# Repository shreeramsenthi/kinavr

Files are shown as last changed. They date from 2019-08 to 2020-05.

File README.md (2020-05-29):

kinavr
=======================================================================================

Hardware and firmware for automated approach to the recording of animal kinematics using inertial measurement units and AVR microcontrollers.

The schematics and board layouts for the modular data loggers can be found in the `board_design` subdirectory.
The source code for the firmware for data loggers make up the rest of the repository.

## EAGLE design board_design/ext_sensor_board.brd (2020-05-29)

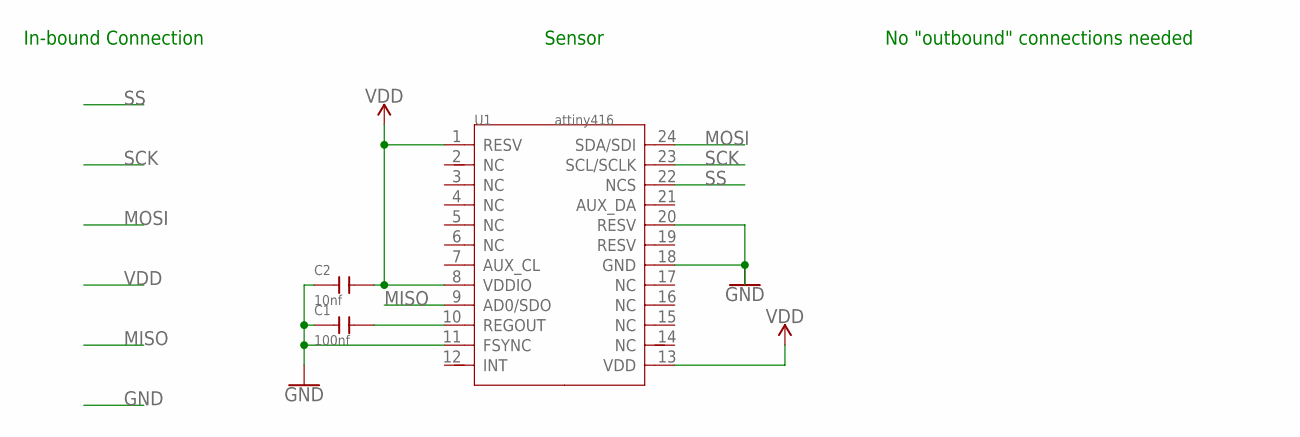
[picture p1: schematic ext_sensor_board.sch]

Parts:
C1: 100nf; C0402
C2: 10nf; C0402
U1: attiny416; QFN24G-0.4-3X3MM

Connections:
GND: C1.1, C2.1, U1.11 (FSYNC), U1.18 (GND), U1.20 (RESV)
MISO: U1.9 (AD0/SDO)
MOSI: U1.24 (SDA/SDI)
unnamed: C1.2, U1.10 (REGOUT)
SCK: U1.23 (SCL/SCLK)
SS: U1.22 (NCS)
VDD: C2.2, U1.1 (RESV), U1.8 (VDDIO), U1.13 (VDD)

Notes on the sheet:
Sensor
In-bound Connection
No "outbound" connections needed

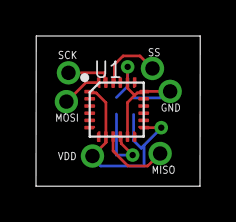
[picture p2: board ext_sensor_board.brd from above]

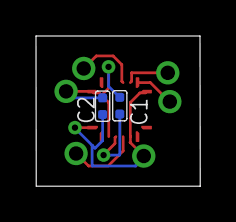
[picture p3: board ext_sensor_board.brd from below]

Board: 2 copper layers, 9.1 x 8.3 mm, 3 parts (2 on the bottom side), 3 nets.

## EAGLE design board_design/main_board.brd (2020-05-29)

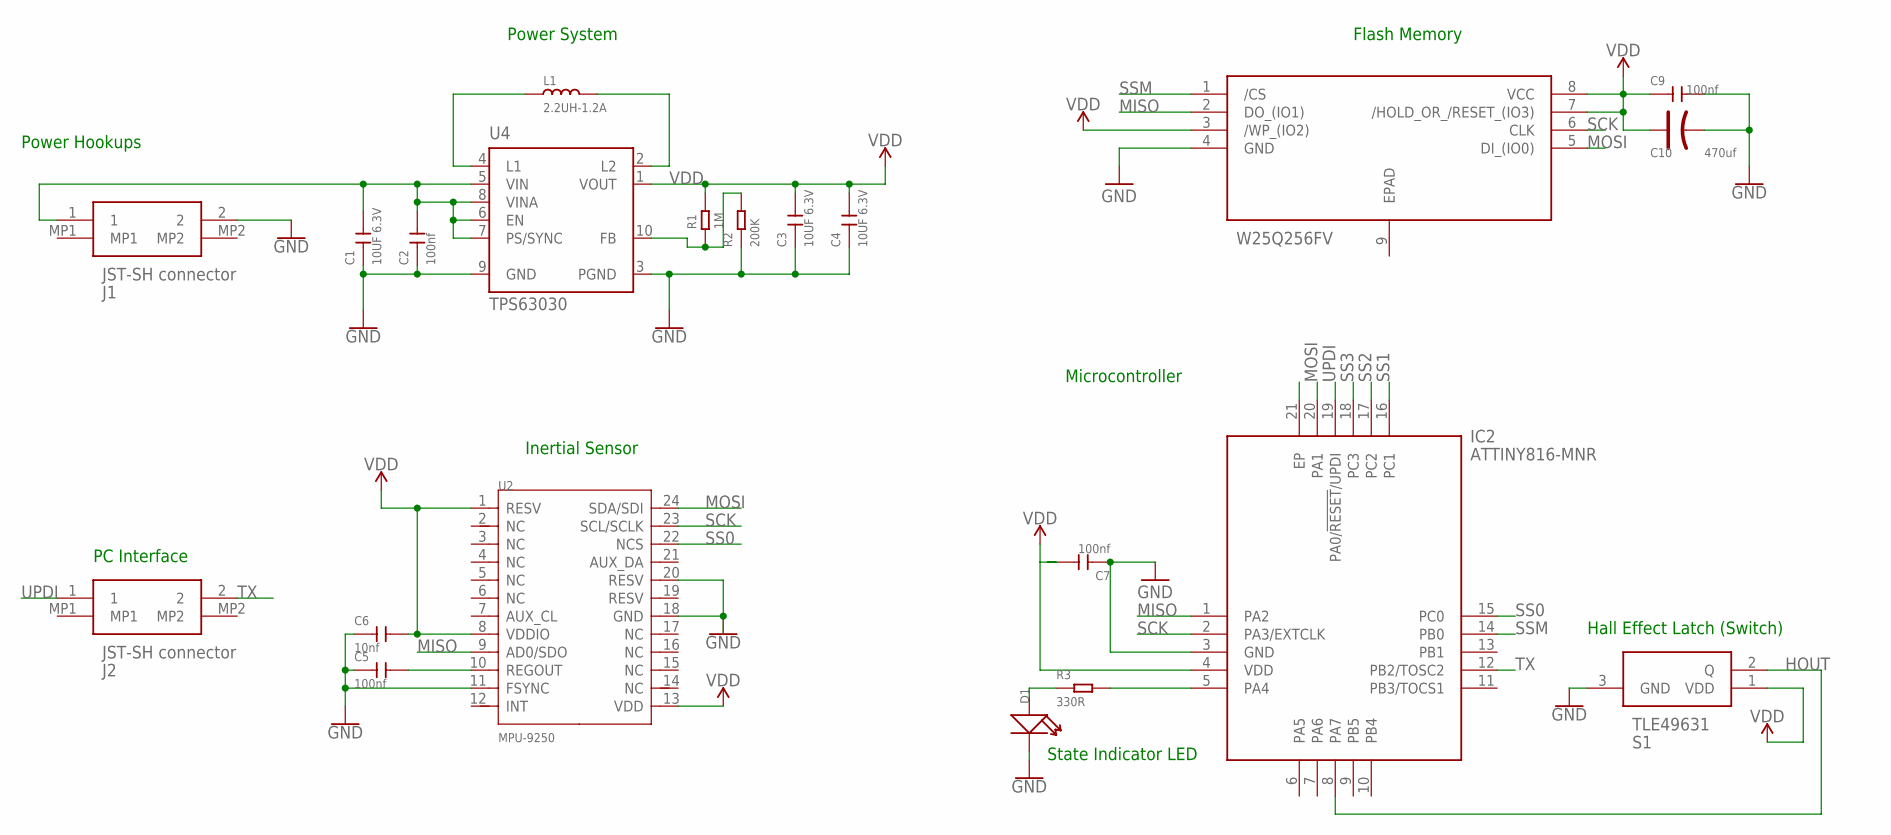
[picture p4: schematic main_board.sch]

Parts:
C1, C3, C4: 10UF 6.3V; C0603
C2, C7, C9: 100nf; C0603
C5: 100nf; C0402
C6: 10nf; C0402
C10: 470uf; AVX-D
D1: YELLOW-0603; LED-0603
IC1: W25Q256FV; SON127P800X600X80-9N
IC2: ATTINY816-MNR; QFN40P300X300X90-21N
J1, J2: JST-SH connector; BM02BSRSSTBLFSN
L1: 2.2UH-1.2A; L0805
R1: 1M; R0402
R2: 200K; R0603
R3: 330R; R0402
S1: TLE49631; SOT95P240X110-3N
U2: MPU-9250; QFN24G-0.4-3X3MM
U4: TPS63030; DRC-S-PVSON-N10

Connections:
GND: C1.1, C2.1, C3.1, C4.1, C5.1, C6.1, C7.1, C9.2, C10.-, D1.-, IC1.4 (GND), IC2.3 (GND), J1.2, R2.1, S1.3 (GND), U2.11 (FSYNC), U2.18 (GND), U2.20 (RESV), U4.3 (PGND), U4.9 (GND)
HOUT: IC2.8 (PA7), S1.2 (Q)
MISO: IC1.2 (DO_(IO1)), IC2.1 (PA2), U2.9 (AD0/SDO)
MOSI: IC1.5 (DI_(IO0)), IC2.20 (PA1), U2.24 (SDA/SDI)
unnamed: D1.+, R3.1
unnamed: L1.1, U4.4 (L1)
unnamed: L1.2, U4.2 (L2)
unnamed: R1.1, R2.2, U4.10 (FB)
unnamed: C1.2, C2.2, J1.1, U4.5 (VIN), U4.6 (EN), U4.7 (PS/SYNC), U4.8 (VINA)
unnamed: IC2.5 (PA4), R3.2
unnamed: C5.2, U2.10 (REGOUT)
SCK: IC1.6 (CLK), IC2.2 (PA3/EXTCLK), U2.23 (SCL/SCLK)
SS0: IC2.15 (PC0), U2.22 (NCS)
SS1: IC2.16 (PC1)
SS2: IC2.17 (PC2)
SS3: IC2.18 (PC3)
SSM: IC1.1 (/CS), IC2.14 (PB0)
TX: IC2.12 (PB2/TOSC2), J2.2
UPDI: IC2.19 (PA0/!RESET!/UPDI), J2.1
VDD: C3.2, C4.2, C6.2, C7.2, C9.1, C10.+, IC1.3 (/WP_(IO2)), IC1.7 (/HOLD_OR_/RESET_(IO3)), IC1.8 (VCC), IC2.4 (VDD), R1.2, S1.1 (VDD), U2.1 (RESV), U2.8 (VDDIO), U2.13 (VDD), U4.1 (VOUT)

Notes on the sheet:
Microcontroller
Power Hookups
PC Interface
Hall Effect Latch (Switch)
State Indicator LED
Power System
Flash Memory
Inertial Sensor

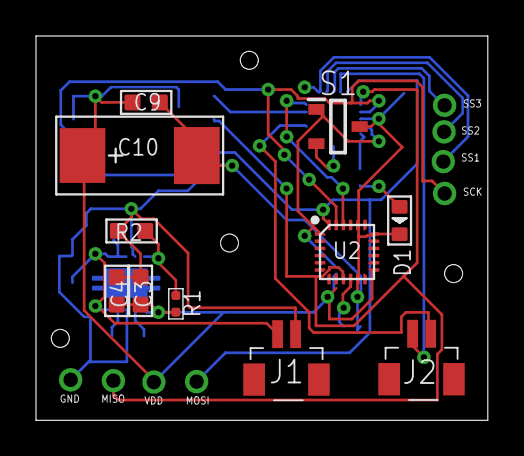
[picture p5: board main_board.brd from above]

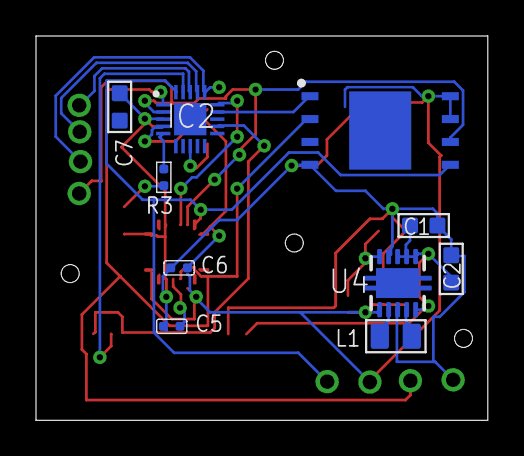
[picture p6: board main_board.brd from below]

Board: 2 copper layers, 25.1 x 21.4 mm, 21 parts (10 on the bottom side), 17 nets.

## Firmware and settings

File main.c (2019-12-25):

#define F_CPU 16000000UL

#include <avr/io.h>
#include <avr/interrupt.h>
#include <util/delay.h>

const int LED_PIN = PIN4_bm;    // PORT A
const int SWITCH_PIN = PIN7_bm; // PORT A

void blink (int blinks) {
  for(int i = 0; i < blinks; i ++){
    PORTA_OUTSET = LED_PIN;
    _delay_ms(500);
    PORTA_OUTCLR = LED_PIN;
    _delay_ms(500);
  }
}

#include "com/uart.c"
#include "com/spi.c"

#include "modes/do.c"
#include "modes/dc.c"

int main () {
  // Setup master clock speed
  CPU_CCP = CCP_IOREG_gc; // Unlock protected io regs
  CLKCTRL_MCLKCTRLB = 0; // set clock speed to 16MHz

  // Hall effect switch setup
  PORTA_DIRCLR = SWITCH_PIN;
  PORTA_PIN7CTRL = PORT_PULLUPEN_bm;

  // LED setup
  PORTA_DIRSET = LED_PIN;
  PORTA_OUTSET = LED_PIN;

  while(1){
    if (~PORTA_IN & SWITCH_PIN) { // check if switch is low
      PORTA_OUTCLR = LED_PIN;
      _delay_ms(5000);
      if(PORTA_IN & SWITCH_PIN) // if switched to high
        collect_data();
      else
        output_data();
    }
    _delay_ms(1000);
  }
}

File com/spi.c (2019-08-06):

#include "mpu9250.h"

const uint8_t MOSI = PIN1_bm; // PORT A
const uint8_t SCK = PIN3_bm; // PORT A
const uint8_t SS_MEM = PIN0_bm; // PORT B
const uint8_t SS_SEN0 = PIN0_bm; // PORT C
const uint8_t SS_SEN1 = PIN1_bm; // PORT C
const uint8_t SS_SEN2 = PIN2_bm; // PORT C
const uint8_t SS_SEN3 = PIN3_bm; // PORT C
const uint8_t SS_SEN = PIN0_bm | PIN1_bm | PIN2_bm | PIN3_bm; // PORT C

/*------------------------------------------*/
/*               Low Level                  */
/*------------------------------------------*/

void spi_init() {
  // Setup output pins, drive SS lines high
  PORTA_DIRSET = MOSI | SCK;

  PORTB_DIRSET = SS_MEM;
  PORTB_OUTSET = SS_MEM;

  PORTC_DIRSET = SS_SEN;
  PORTC_OUTSET = SS_SEN;

  SPI0_CTRLB = 3; // SPI MODE 3
  SPI0_CTRLA = SPI_MASTER_bm |
               SPI_PRESC_DIV16_gc |
               SPI_ENABLE_bm; // Enable SPI in fast master mode
}

unsigned char spi_transfer (unsigned char data) {
  SPI0_DATA = data; // Place data in transfer register
  while(!(SPI0_INTFLAGS & SPI_IF_bm)); // Wait until SPI Interrupt Flag is set
  return(SPI0_DATA);
}

/*------------------------------------------*/
/*            Flash Functions               */
/*------------------------------------------*/

void flash_send_address (uint32_t addr) { //Sends 3 byte addresses over SPI
  // Convert address to 3 bytes and send
  spi_transfer((addr >> 16) & 0xFF);
  spi_transfer((addr >> 8) & 0xFF);
  spi_transfer(addr & 0xFF);
}

void flash_wait_for_ready ()
{
  PORTB_OUTCLR = SS_MEM; // Set SS low
  spi_transfer(0x05); // Read status register 1 command
  while((spi_transfer(0) & 1)); // Keep reading until least bit = 0, indicates not chip isn't busy
  PORTB_OUTSET = SS_MEM; // Set SS High
}

void flash_write_enable () {
  PORTB_OUTCLR = SS_MEM; // Set SS low
  spi_transfer(0x06); //Write enable
  PORTB_OUTSET = SS_MEM; // Set SS High
}

// For external use
void flash_start_read (uint32_t addr) {
  flash_wait_for_ready();

  PORTB_OUTCLR = SS_MEM;   // Set SS low
  spi_transfer(0x03); // Read Command
  flash_send_address(addr);
}

void flash_start_write (uint32_t addr){
  flash_wait_for_ready();
  flash_write_enable();

  PORTB_OUTCLR = SS_MEM; // Set SS low
  spi_transfer(0x02); // Write command
  flash_send_address(addr);
}

void flash_end_rw () {
  PORTB_OUTSET = SS_MEM;   // Set SS high
}

void flash_write_single (uint32_t addr, unsigned char data){
  flash_wait_for_ready();
  flash_write_enable();

  PORTB_OUTCLR = SS_MEM; // Set SS low
  spi_transfer(0x02); // Write command
  flash_send_address(addr);
  spi_transfer(data);
  PORTB_OUTSET = SS_MEM; // End Write
}

void flash_block_erase (uint32_t addr){
  flash_wait_for_ready();
  flash_write_enable();

  PORTB_OUTCLR = SS_MEM; // Set SS low
  spi_transfer(0x52); // Block Erase command
  flash_send_address(addr);
  PORTB_OUTSET = SS_MEM; // End Write
}

void flash_chip_erase (){
  flash_wait_for_ready();
  flash_write_enable();

  PORTB_OUTCLR = SS_MEM; // Set SS low
  spi_transfer(0xC7); // Chip Erase command
  PORTB_OUTSET = SS_MEM; // End Write
}

/*------------------------------------------*/
/*            Sensor Functions              */
/*------------------------------------------*/

uint8_t mpu_reg_transfer (uint8_t SS, uint8_t reg, uint8_t val) {
  PORTC_OUTCLR = SS;
  spi_transfer(reg);
  uint8_t data = spi_transfer(val);
  PORTC_OUTSET = SS;
  return(data);
}

void mpu_write_register (uint8_t SS, uint8_t addr, uint8_t data) {
  mpu_reg_transfer(SS, addr, data);
  _delay_ms(10);
}

void mpu_start_read (uint8_t SS, uint8_t addr) {
  PORTC_OUTCLR = SS;
  spi_transfer(addr | 0x80); // Strip bank info, add read flag
}

void mpu_end_read (uint8_t SS) {
  PORTC_OUTSET = SS;
}

void mag_write_reg (uint8_t SS, uint8_t reg, uint8_t data) {
  mpu_write_register(SS, MPU9250_I2C_SLV0_ADDR, 0x0C); // Set i2c Address to write
  mpu_write_register(SS, MPU9250_I2C_SLV0_REG, reg); // Set register address
  mpu_write_register(SS, MPU9250_I2C_SLV0_DO, data); // Set value to write
}

void mag_start_read (uint8_t SS, uint8_t reg) {
  mpu_write_register(SS, MPU9250_I2C_SLV0_ADDR, 0x0C | 0x80); // Set i2c Address to read
  mpu_write_register(SS, MPU9250_I2C_SLV0_REG, reg); // Set register address
  mpu_write_register(SS, MPU9250_I2C_SLV0_DO, 0xFF); // Set value to write
}

void sensor_init (uint8_t SS) {
  // Reset Sensor
  mpu_write_register(SS, MPU9250_PWR_MGMT_1, MPU9250_BIT_H_RESET);
  _delay_ms(100);
  mpu_write_register(SS, MPU9250_USER_CTRL, MPU9250_BIT_I2C_IF_DIS); // SPI mode
  mpu_write_register(SS, MPU9250_PWR_MGMT_1, 0x00); // Clear sleep mode
  mpu_write_register(SS, MPU9250_PWR_MGMT_2, 0x00); // Ensure Accel + Gyro are enabled

  // Set Accel/Gyro resolution and LP Filter
  mpu_write_register(SS, MPU9250_ACCEL_CONFIG, 0x00); // 2G scale
  mpu_write_register(SS, MPU9250_GYRO_CONFIG, 0x00); // Enable LP filter and 250 scale (may be disabling LP filter, unclear)

  // Set up I2C Master
  mpu_write_register(SS, MPU9250_INT_PIN_CFG, 0x20); // Disable bypass and latch INT pin
  mpu_write_register(SS, MPU9250_I2C_MST_CTRL, 0x0D); // set I2C master clock at 400kHz
  mpu_write_register(SS, MPU9250_I2C_MST_DELAY_CTRL, 0x01); // Set magnetometer delay
  mpu_write_register(SS, MPU9250_USER_CTRL, MPU9250_BIT_I2C_IF_DIS | MPU9250_BIT_I2C_MST_EN); // Enable I2C master mode

  // Reset Mag
  mag_write_reg(SS, REG_AK8963_CNTL2, BIT_AK8963_CNTL2_SRST); // Reset magnetometer
  mpu_write_register(SS, MPU9250_I2C_SLV0_CTRL, 0x80); // Enable SLV0 and no read
  _delay_ms(100);
  mag_write_reg(SS, REG_AK8963_CNTL1, 0b0110); // Continous mode, 100Hz
  mpu_write_register(SS, MPU9250_I2C_SLV0_CTRL, 0x80); // Enable SLV0 and no read

  // Prep mag for reading
  mpu_write_register(SS, MPU9250_I2C_SLV0_CTRL, 0x87); // Enable SLV0 and 7 bytes of read
  mag_start_read(SS, 0x03); // data register on the mag
}

void sensor_sample (uint8_t SS, uint32_t addr) {
  uint8_t sample[18];

  // Read in data from sensor
  mpu_start_read(SS, MPU9250_ACCEL_XOUT_H);
  for (int i = 0; i < 6; i++)
    sample[i] = spi_transfer(0x00);
  spi_transfer(0x00); // Disregard two bytes of temperature
  spi_transfer(0x00);
  for (int i = 6; i < 18; i++)
    sample[i] = spi_transfer(0x00);
  mpu_end_read(SS);

  // Write to memory
  flash_start_write(addr);
  for(int i = 0; i < 18; i++)
    spi_transfer(sample[i]);
  flash_end_rw();
}

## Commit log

2019-07-30 Add uart initialization
2019-07-30 More timer testing
2019-07-31 Test button ISR
2019-07-31 Test non-ISR buttons
2019-07-31 Swap bit maps from int to uint8_t
    [spi.c, uart.c]
2019-07-31 Minor SPI reorganization
2019-07-31 Add sensor tests
2019-07-31 Add sensor header file
2019-08-01 Add testing for writing samples to mem
2019-08-03 Initialize fuse setting
2019-08-03 Add source for fuse setting
2019-08-03 Switch all modes to 16MHz
2019-08-03 Test 500Hz sampling
2019-08-03 Test 400Hz
2019-08-03 Test sample rate with bool flags
2019-08-03 Test 500Hz with ISR flags
2019-08-06 Fix math error in finding end of page
    [do.c]
2019-08-06 Add testing for memory address fix
    [do.c]
2019-12-06 Add hex for polling sensor
2019-12-24 Test new mag switch
2019-12-24 Test blinking, 400Hz, and post-erase indication
2019-12-24 Add break between x and z calibration
2019-12-25 Stop timer more effectively
2019-12-27 Fix mixed indent in do
    [do.c]
2020-05-29 Add board designs
    [ext_sensor_board.brd, ext_sensor_board.sch, main_board.brd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]

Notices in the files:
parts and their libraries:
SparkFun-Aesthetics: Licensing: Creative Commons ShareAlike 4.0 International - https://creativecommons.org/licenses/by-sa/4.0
